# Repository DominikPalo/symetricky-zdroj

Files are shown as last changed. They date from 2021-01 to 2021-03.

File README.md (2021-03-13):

# Miniatúrny symetrický zdroj +/-5V, +/-12V s ochranou proti skratu

Repozitár obsahuje všetky potrebné iformácie k stavbe zdroja. Autorom elektro dizajnu (DPS a schéma) je David Čada (alias Davidus / Drirr90). Nakoľko sa jedná o šikovný zdroj pre domáce použite, v tomto repozitári nájdete dokumentáciu a materiály, ktoré som vytvoril pri jeho konštrukcii. Video s podrobným opisom zdroja nájdete na: https://youtu.be/iAIXDw9BsSQ.

## Obsah repozitára
1. Pôvodná schéma zapojenia a PCB vo formáte EAGLE (autor: David Čada)
1. Gerber súbory potrebné k výrobe DPS (JLCPCB, PCBWay, ...)
1. [Zoznam použitých komponentov (BOM)](BOM.md) aj s odkazmi na distribútorov TME a GME
1. 3D model krabičky na zdroj vhodný k tlači na 3D tlačiarni
1. Fotodokumetáciu mojej konštrukcie (pridám neskôr)

## Info od autora eletkro dizajnu:
>1. Pouze k nekomercnimu pouziti.
>1. Pokud chcete prezentovat zdroj i jinde, tak pouze s temito podminkami pouziti + odkaz na zdroj https://youtu.be/iAIXDw9BsSQ
>1. Rad zodpovim jakekoli dotazy na adrese cada.david zavinac gmail.com

## 3D krabička
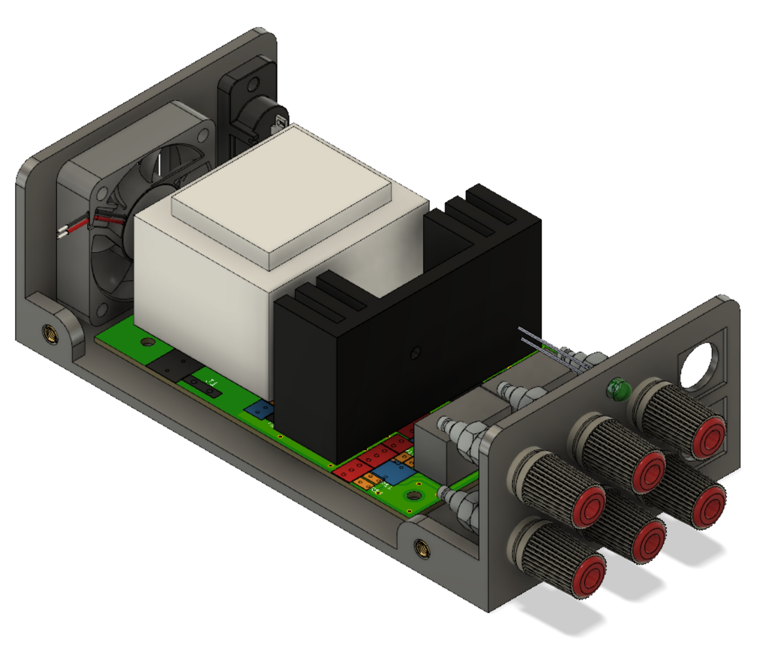
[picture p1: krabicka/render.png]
Krabicka

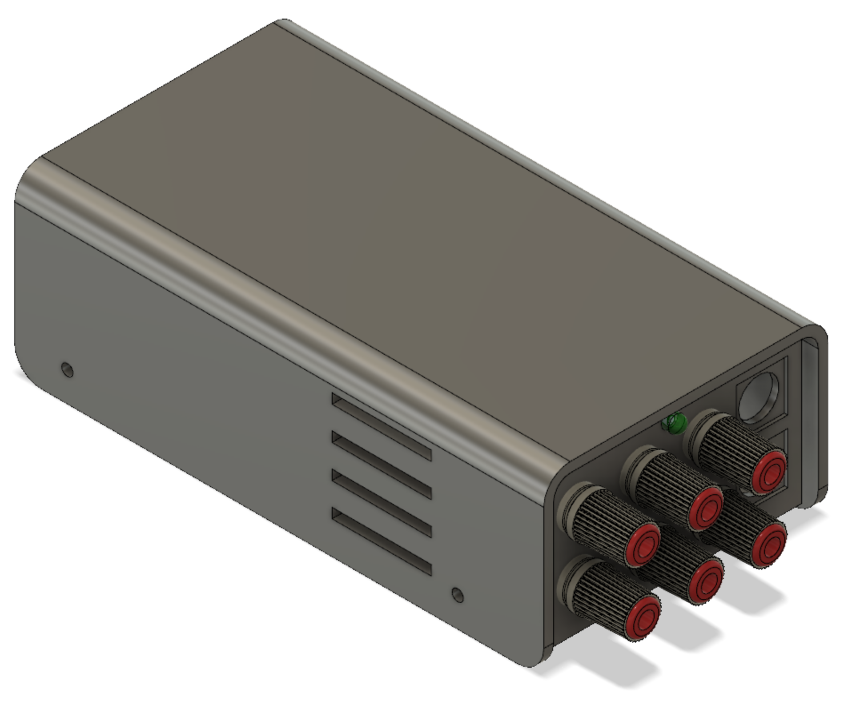
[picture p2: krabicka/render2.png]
Krabicka2


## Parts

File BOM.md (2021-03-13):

## Komponenty na DPS

| Označenie | Typ | Púzdro | Počet | TME.eu | GM Electronic | &nbsp;Cena&nbsp;
|---|-----|---|---|---|---|-----
| TR1 | TSZZ12/010M INDEL | EI48-2 | 1x | [TSZZ10/2X15V](https://www.tme.eu/sk/details/tszz10_2x15v/transformatory-pre-pcb/indel/tszz12-010m/) | N/A | 4,04 €
| D1, D2, D3, D4 | 1N4007 | DO41 | 4x | [1N4007-CDI](https://www.tme.eu/sk/details/1n4007-cdi/univerzalne-diody-tht/cdil/1n4007/) | [220-002](https://www.gme.sk/dioda-1n4007) | 0,25 €
| T2 | BC337 | TO92| 1x | [BC337-25](https://www.tme.eu/sk/details/bc337-25/tranzistory-npn-tht/semtech-electronics-limited/bc337-25-bulk/) | [210-018](https://www.gme.sk/bipolarni-tranzistor-bc337-25-to92) | 0,07 €
| T5 | BT149 | TO92 | 1x | [BT149D](https://www.tme.eu/sk/details/bt149d/tyristory-tht/ween-semiconductors/bt149d-112/) | [224-039](https://www.gme.sk/tyristor-bt149d) | 0,18 €
| T6 | MPSA44 | TO92 | 1x | [MPSA44-DIO](https://www.tme.eu/sk/details/mpsa44-dio/tranzistory-npn-tht/diotec-semiconductor/mpsa44/) | [212-077](https://www.gme.sk/bipolarni-tranzistor-mpsa44-to92) | 0,17 €
| T7, T8 | BC327 | TO92  | 2x | [BC327-16](https://www.tme.eu/sk/details/bc327-16/tranzistory-pnp-tht/diotec-semiconductor/) | [210-012](https://www.gme.sk/bipolarni-tranzistor-bc327-16-to92) | 0,16 €
| J1, J2 | Faston 6,3x0,8mm THT | F061.100 | 2x | [3866A.68 VOGT](https://www.tme.eu/sk/details/3866a.68/spajkovacie-kontakty-do-pcb/vogt/) | [834-010](https://www.gme.sk/faston-do-plosneho-spoje-fvp-6-3x0-8-cinovany) | 0,16 €
| RLY3, RLY4 | 5V/167Ω | RG5V2 | 2x | [RS-5](https://www.tme.eu/sk/details/rs-5/elektromagneticke-rele-miniaturne/recoy-rayex-electronics/) | [634-855](https://www.gme.sk/releg5v2-05lr) | 2,52 €
| B1 | DF06S | DFS | 1x | [DF06S](https://www.tme.eu/sk/details/df06s/mostiky-jednofazove-diodove-smd-tht/on-semiconductor/) | [924-009](https://www.gme.sk/diodovy-mustek-b250c1000smd) | 0,17 €
| K1, K2, K3 | PSH02-02P (KK 254) | PSH02-02P | 3x | [MX-22-23-2031](https://www.tme.eu/sk/details/mx-22-23-2031/signalove-konektory-raster-2-54mm/molex/22-23-2031/) | [800-164](https://www.gme.sk/konektor-se-zamkem-psh02-03pg) | 0,34 €
| K4, K5 | PSH02-03P (KK 254) | PSH02-03P | 2x | [MX-22-23-2021](https://www.tme.eu/sk/details/mx-22-23-2021/signalove-konektory-raster-2-54mm/molex/22-23-2021/) | [800-163](https://www.gme.sk/konektor-se-zamkem-psh02-02pg) | 0,22 €
| F1 | T200mA TR5 | 19560 | 1x | [0034.6608](https://www.tme.eu/sk/details/0034.6608/poistky-tr5-pomale/schurter/) | [633-202](https://www.gme.sk/pojistka-radialni-schurter-mst-250-200ma-sw) | 0,51 €
| 7805 | L7805ACV-DG | TO-220S | 1x | [L7805ACV-DG](https://www.tme.eu/sk/details/l7805acv-dg/stabilizatory-napatia-neregulovane/stmicroelectronics/) | [330-149](https://www.gme.sk/stabilizator-pevneho-napeti-st-microelectronics-thomson-7805cv-stm) | 0,35 €
| 7905 | L7905ACV-DG | TO-220S | 1x | [L7905ACV](https://www.tme.eu/sk/details/l7905acv/stabilizatory-napatia-neregulovane/stmicroelectronics/) * | [330-023](https://www.gme.sk/stabilizator-pevneho-napeti-7905-to220) | 0,34 €
| 7812 | L7812ACV-DG | TO-220S | 1x | [L7812ACV-DG](https://www.tme.eu/sk/details/l7812acv-dg/stabilizatory-napatia-neregulovane/stmicroelectronics/) | [330-005](https://www.gme.sk/stabilizator-pevneho-napeti-st-microelectronics-thomson-7812cv-dg-stm) | 0,39 €
| 7912 | L7912ACV-DG | TO-220S | 1x | [L7912ACV-DG](https://www.tme.eu/sk/details/l7912acv-dg/stabilizatory-napatia-neregulovane/stmicroelectronics/) | [330-026](https://www.gme.sk/stabilizator-pevneho-napeti-taiwan-semiconductor-7912) | 0,51 €
| C1, C8, C14, C15, C16, C17 | 100 nF | CK | 6x | [CC-100N](https://www.tme.eu/sk/details/cc-100n/keramicke-kondenzatory-tht-50v/sr-passives/) | [120-060](https://www.gme.sk/ck-100n-63v-y5v-rm5-08-80-20) | 0,30 € 
| C3, C4, C5, C6, C20 | 47 μF | CT12/RM5 | 5x | [SS1E476M6L007PA580](https://www.tme.eu/sk/details/ss1e476m6l007pa580/elektrolyticke-kondenzatory-tht-85degc/samwha/) | [123-093](https://www.gme.sk/ce-47u-16v-jam-ss-6-3x7-rm2-5-bulk) | 0,30 €
| C9, C21, C22 | 4,7 μF | E2,5-6 | 3x | [PF2C4R7MNN6311U](https://www.tme.eu/sk/details/pf2c4r7mnn6311u/elektrolyticke-kondenzatory-tht-105degc/elite/) | [123-034](https://www.gme.sk/ce-4-7u-160v-jam-sk-6-3x11-rm2-5-bulk) | 0,27 €
| C10, C11, C12, C13 | 470 μF / 25V | CT12/RM5/⌀8 | 4x | [EEUFR1E471LB](https://www.tme.eu/sk/details/eeufr1e471lb/elektrolyticke-kondenzatory-tht-105degc/panasonic/) | [123-469](https://www.gme.sk/ce-470u-25v-samw-sd-8x12-rm3-5-ammo) | 0,60 €
| C18, C19 | 47 μF / 35 V | E2,5-6 | 2x | [JRG-47U/35](https://www.tme.eu/sk/details/jrg-47u_35/elektrolyticke-kondenzatory-tht-105degc/jb-capacitors/jrg1v470m02500630115000b/) | [123-660](https://www.gme.sk/ce-47u-50vt-hit-ehr-6-3x11-rm2-5-bulk) | 0,12 €
| R1, R2 | 1R5/1W | 0411V | 2x | [1W-1R5](https://www.tme.eu/sk/details/1w-1r5/metalizovane-rezistory-tht-1w/royal-ohm/mor01sj015ja10/) | [114-489](https://www.gme.sk/rm-1r5-0309-1w-1) | 0,20 €
| R3, R4, R6, R15 | 4k7 | 0207/2V | 4x
| R5 | 330 | 0207/2V | 1x
| R7 | 47k | 0207/2V | 1x
| R8, R9, R10, R13, R14 | 10k | 0207/2V | 5x
| R11, R12 | 2k2 | 0207/2V | 2x
| R16 | 12 | 0207/2V | 1x

\* TME nema v ponuke dual-gauge verziu L7905ACV (suffix -DG), preto je potrebne pri montazi na chladic zbrusit izolacnu priechodku (IB6)
\** GME nema v ponuke presnejsie verzie (suffix A)

## Ostatné komponenty

| Položka | Počet kusov | TME.eu  | GM Electronic | Cena | Poznámka
|---|---|---|---|---|---
| Izolačná priechodka TO220| 4x | [IB-6](https://www.tme.eu/sk/details/ib-6/chladice-prislusenstvo/fischer-elektronik/ib-6/) | [621-012](https://www.gme.sk/ib2) | 0,32 €
| Silikónová teplovodivá podložka TO220 | 4x | [SMICA-TO220](https://www.tme.eu/sk/details/smica-to220/chladice-prislusenstvo/ninigi/smica-to220/) | [621-035](https://www.gme.sk/silikonova-teplovodiva-podlozka-to-220) | 0,52 €
| Konektor KK 254 na kábel (3-pin) | 3x | [MX-22-01-3037](https://www.tme.eu/sk/details/mx-22-01-3037/signalove-konektory-raster-2-54mm/molex/22-01-3037/) | [800-085](https://www.gme.sk/konektor-se-zamkem-pfh02-03p) | 0,09 €
| Konektor KK 254 na kábel (2-pin) | 2x | [MX-22-01-3027](https://www.tme.eu/sk/details/mx-22-01-3027/signalove-konektory-raster-2-54mm/molex/22-01-3027/) | [800-084](https://www.gme.sk/konektor-se-zamkem-pfh02-02p) | 0,06 €
| Kontakt konektora KK 254 | 13x | [MX-08-55-0102](https://www.tme.eu/sk/details/mx-08-55-0102/signalove-konektory-raster-2-54mm/molex/08-55-0102/) | [800-162](https://www.gme.sk/kontakt-pff02-01fg) | 1,30 €
| Chladič | 1x | N/A | N\A | 3,02 € | [GES.cz: CH 13/35](https://www.ges.cz/cz/ch-13-35-GES06800505.html)
| Napájací konektor IEC C8 | 1x | [GZ-01](https://www.tme.eu/sk/details/gz-01/konektory-iec-60320/) | [806-029](https://www.gme.sk/napajeci-mini-konektor-schurter-lw6130-4300-0096) | 1,34 €
| LED 5mm R/G | 1x | [LL-509VUGM2E-V11A](https://www.tme.eu/sk/details/ll-509vugm2e-v11a/led-diody-tht-5mm/luckylight/ll-509vugm2e-v11a-2b/) | [511-838](https://www.gme.sk/led-5mm-rg-cc-60-50-60-l-59egw) |0,32 €
| Zdierka (červená) | 2x | [BS-244DSM-R](https://www.tme.eu/sk/details/bs-244dsm-r/zdierky-pre-bananiky-4mm/) | [811-208](https://www.gme.sk/zdirka-panelova-4mm-cervena-24-829-1) | 1,40 € | [AliExpress](https://www.aliexpress.com/item/32871905530.html)
| Zdierka (modrá) | 2x | [BS-244DSM-BL](https://www.tme.eu/sk/details/bs-244dsm-bl/zdierky-pre-bananiky-4mm/) | N/A | 1,40 € | [AliExpress](https://www.aliexpress.com/item/32871905530.html)
| Zdierka (čierna) | 2x | [BS-244DSM-B](https://www.tme.eu/sk/details/bs-244dsm-b/zdierky-pre-bananiky-4mm/) | [811-209](https://www.gme.sk/zdirka-panelova-4mm-cerna-24-829-2) | 1,40 € | [AliExpress](https://www.aliexpress.com/item/32871905530.html)
| Kolískový vypínač | 1x | 
| Krabička | 1x | N\A | N/A | 3,44 € | 3D tlac, [GES.cz: KG B15](https://www.ges.cz/cz/kg-b15-GES07200015.html)

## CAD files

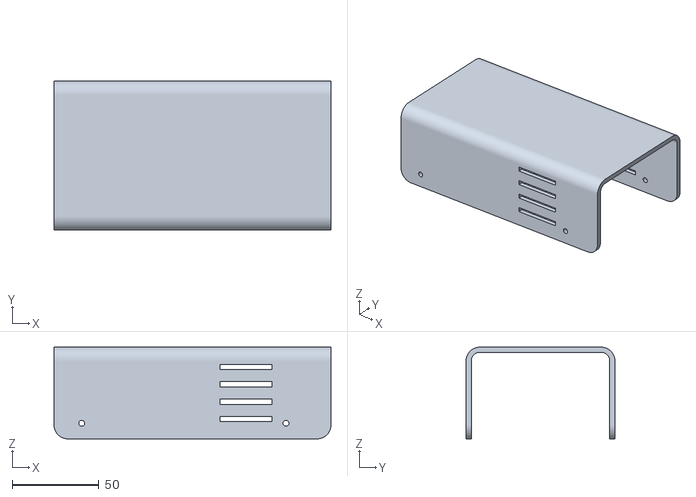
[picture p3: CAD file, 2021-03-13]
krabicka/top.stl
160.0 x 86.0 x 53.0

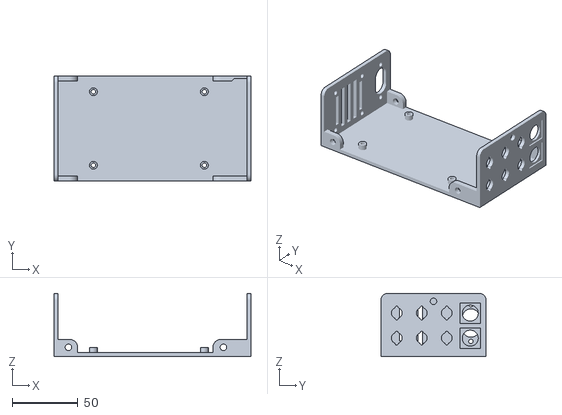
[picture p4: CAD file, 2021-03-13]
krabicka/bottom.stl
150.0 x 80.0 x 48.0

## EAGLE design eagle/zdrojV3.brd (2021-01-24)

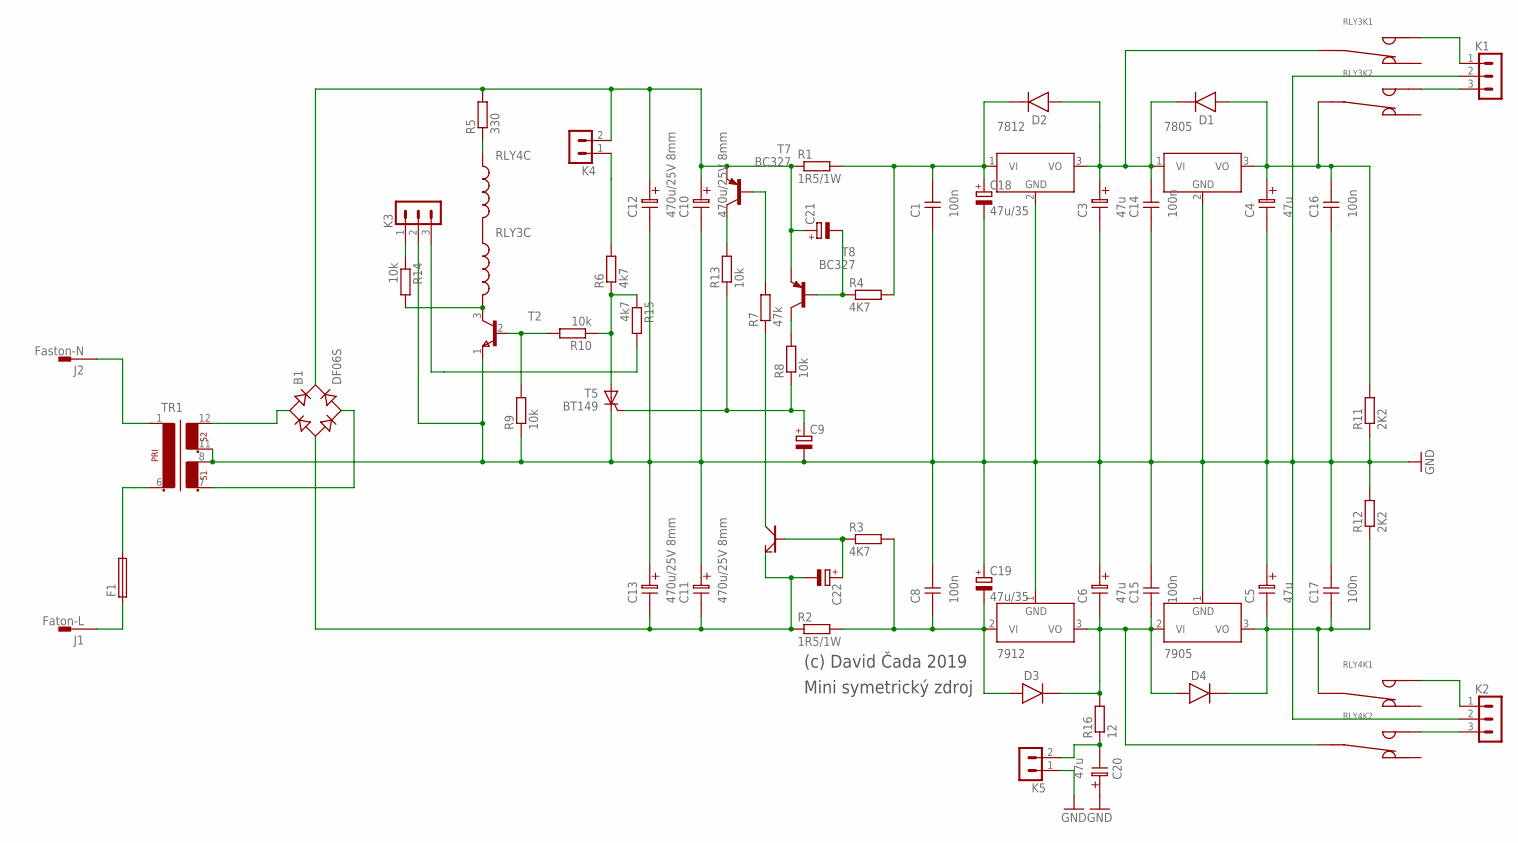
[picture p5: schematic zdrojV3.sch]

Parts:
7805: 7812; TO-220S
7812: 7805; TO-220S
7905: 7912; TO-220S
7912: 7905; TO-220S
B1: DF06S; DFS
C1, C8, C14, C15, C16, C17: 100n; CK
C3, C4, C5, C6, C20: 47u; CT12
C9, C21, C22: CPOL-EUE2.5-6; E2,5-6
C10, C11, C12, C13: 470u/25V 8mm; CT12
C18, C19: 47u/35; E2,5-6
D1, D2, D3, D4: 1N4007; DO41
F1: 19560
J1: Faton-L; F061.100
J2: Faston-N; F061.100
K1, K2, K3: PSH02-03P
K4, K5: PSH02-02P
R1, R2: 1R5/1W; 0411V
R3, R4: 4K7; 0207/2V
R5: 330; 0207/2V
R6, R15: 4k7; 0207/2V
R7: 47k; 0207/2V
R8, R9, R10, R13, R14: 10k; 0207/2V
R11, R12: 2K2; 0207/2V
R16: 12; 0207/2V
RLY3, RLY4: RELEG5V2; RG5V2
T2: BC337-40; TO-92C
T5: BT149; TO92-4
T6: MPSA44; TO92-EBC
T7, T8: BC327; TO92
TR1: EI48-2

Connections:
GND: 7805.2 (GND), 7812.2 (GND), 7905.1 (GND), 7912.1 (GND), C1.1, C3.2, C4.2, C5.1, C6.1, C8.2, C9.-, C10.2, C11.1, C12.2, C13.1, C14.1, C15.2, C16.1, C17.2, C18.-, C19.+, C20.1, K1.2, K2.2, K3.2, K5.1, R9.1, R11.1, R12.2, T2.1 (E), T5.C, TR1.8 (4), TR1.11 (5)
LEDGREEN+: K3.3, R15.2
unnamed: R7.2, T7.2 (B)
unnamed: 7805.1 (VI), 7812.3 (VO), C3.1, C14.2, D1.K, D2.A, RLY3.3
unnamed: 7905.2 (VI), 7912.3 (VO), C6.2, C15.1, D3.K, D4.A, R16.2, RLY4.6 (3)
unnamed: 7912.2 (VI), C8.1, C19.-, D3.A, R2.2, R3.2
unnamed: 7812.1 (VI), C1.2, C18.+, D2.K, R1.2, R4.2
unnamed: K1.1, RLY3.5 (1)
unnamed: 7905.3 (VO), C5.2, C17.1, D4.K, R12.1, RLY4.3
unnamed: R13.2, T7.3 (C)
unnamed: R9.2, R10.2, T2.2 (B)
unnamed: C22.+, R3.1, T6.B
unnamed: C21.-, R4.1, T8.2 (B)
unnamed: RLY3.1, RLY4.2
unnamed: R5.1, RLY4.1
unnamed: C9.+, R8.1, R13.1, T5.G
unnamed: R6.1, R10.1, R15.1, T5.A
unnamed: R14.2, RLY3.2, T2.3 (C)
unnamed: K4.1, R6.2
unnamed: K3.1, R14.1
unnamed: R7.1, T6.E (C)
unnamed: R8.2, T8.3 (C)
unnamed: F1.2, TR1.6 (2)
unnamed: B1.+, C10.1, C12.1, C21.+, K4.2, R1.1, R5.2, T7.1 (E), T8.1 (E)
unnamed: B1.AC1, TR1.12 (6)
unnamed: B1.AC2, TR1.7 (3)
unnamed: 7805.3 (VO), C4.1, C16.2, D1.A, R11.2, RLY3.6 (3)
unnamed: B1.-, C11.2, C13.2, C22.-, R2.1, T6.C (E)
unnamed: K1.3, RLY3.8 (1)
unnamed: K2.1, RLY4.5 (1)
unnamed: K2.3, RLY4.8 (1)
unnamed: C20.2, K5.2, R16.1
unnamed: J2.A1, J2.A2, TR1.1
POJISTKA: F1.1, J1.A1, J1.A2

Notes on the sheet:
(c) David Čada 2019
Mini symetrický zdroj

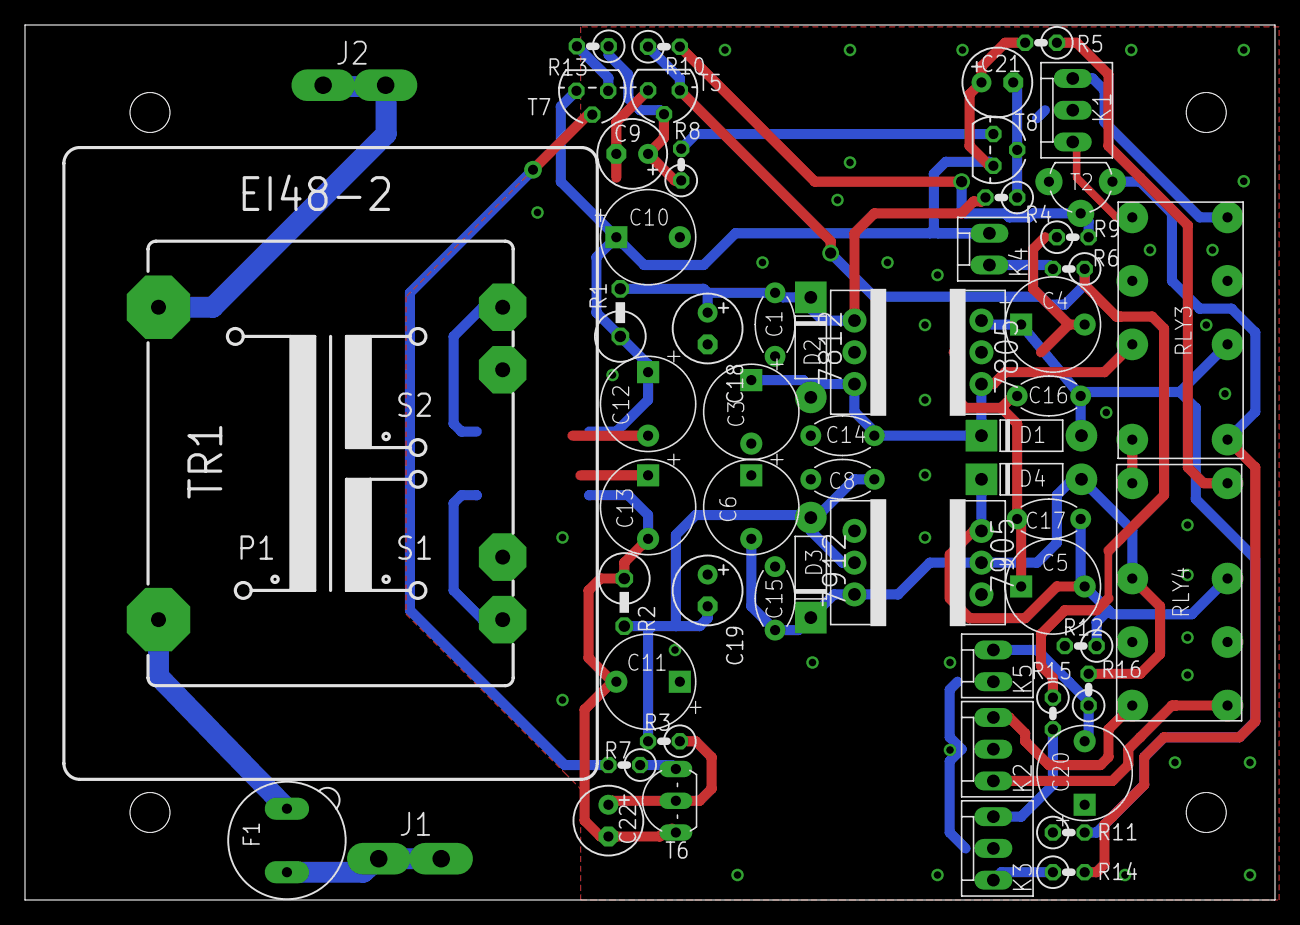
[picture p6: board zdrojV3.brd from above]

Board: 2 copper layers, 100.0 x 70.0 mm, 61 parts (1 on the bottom side), 34 nets.

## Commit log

2021-01-23 Add README and BOM
2021-01-24 Add EAGLE files
    [zdrojV3.brd, zdrojV3.sch]
2021-01-24 Add gerber files
2021-01-24 Add packages, capacitors and resistors to the BOM
2021-03-13 Add case STL files
    [bottom.stl, top.stl]
2021-03-13 Add C9, C21, C22 to BOM

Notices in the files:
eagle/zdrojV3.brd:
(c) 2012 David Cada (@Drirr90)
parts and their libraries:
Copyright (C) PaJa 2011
